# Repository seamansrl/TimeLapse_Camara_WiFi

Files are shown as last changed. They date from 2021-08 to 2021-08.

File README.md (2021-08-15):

# CAMARA TIMELAPSE CON GESTION WIFI

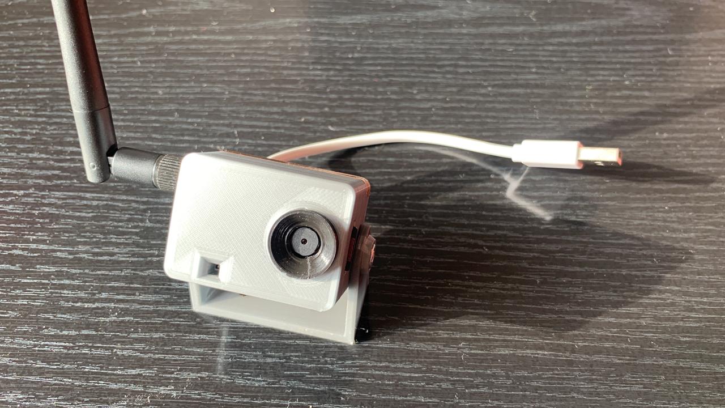
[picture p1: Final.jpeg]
Camara terminada


# Primeros pasos:

Antes de empezar deberemos bajar el proyecto a nuestra PC. Hay en él dos carpetas: una llamada CODIGO y otra llamada CHASIS. En Código esta el programa que deberemos cargar a nuestra ESP32-CAM y en chasis los modelos STL para imprimir la carcaza. 

# Elementos a utilizar

- ESP32-CAM modelo AI_THINKER (El código sirve para cualquier camara pero el chasis solo para esa)
- Antena con pigtail con conector micro para ESP32-CAM (Si se pone la antena externa de deberá cambiar de posición la resistencia interna. Ver más aca: https://randomnerdtutorials.com/esp32-cam-connect-external-antenna/)
- Tornillo rosca métrica de 1/8, 5cm con tuerca
- Cable rojo y negro 
- Conector USB
- Cargador USB de 2,5A
- MicroSD de 32GB formateada en FAT32

# Impresión del chasis

- Es importante imprimir el chasis con una altura de capa de 0,16mm máximo ya que mas allá de este punto puede que la placa no entre o queden las piezas fuera de lugar.
- La velocidad de impresión recomendada es de 40mm/s máximo para obtener buena terminación.
- No se requieren soportes.
- El parasol si se hace de un PLA con un coeficiente de fusion distinto al del chasis puede que cueste que entre ya que la rosca es muy chica. (ISO 17mm con paso de 0,75mm 3 espiras)

# Como cargar el código en la ESP32-CAM

Para copiar el código a la ESP32-Cam se requiere de un adaptador USB-TTL el cual ira conectado de la siguiente manera:

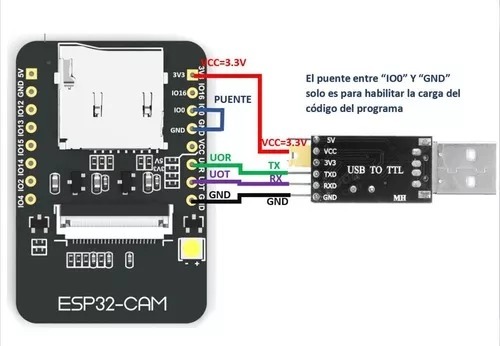
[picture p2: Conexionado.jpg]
Conexion entre TTL y ESP32-Cam


La configuración del entorno arduino para la carga sera:

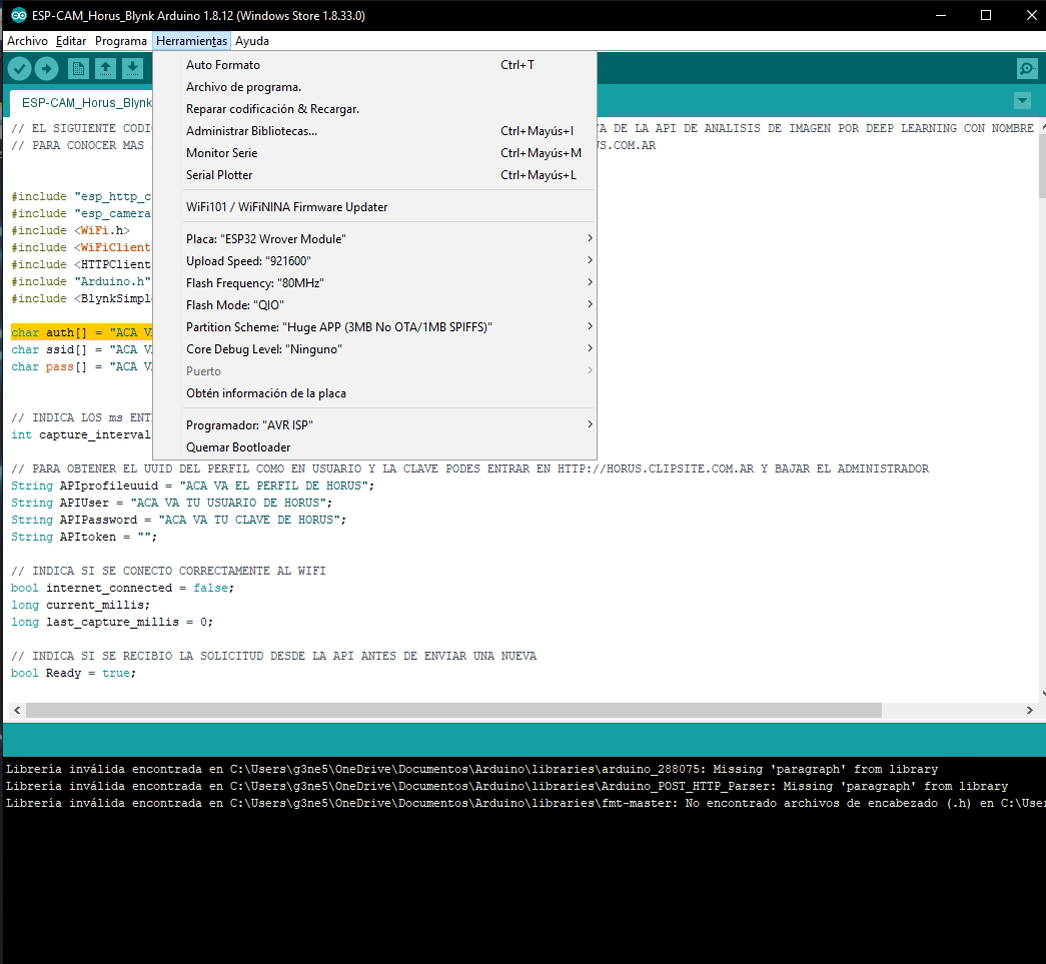
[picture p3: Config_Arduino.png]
Configuracion en entorno Arduino


Nota: Si hay problemas para subir el código a la placa y todo parase corresponder correctamente deberá probar invirtiendo el RX y el TX de la placa TTL.

# Configuración en tiempo de ejecución 

Una vez que el código este compilado y cargado a la ESP32, podremos configurar los parámetros de la camara usando un archivo “JSON” de nombre “config.json”. Desde este podremos cambiar los ajustes de imagen según la siguiente tabla: 

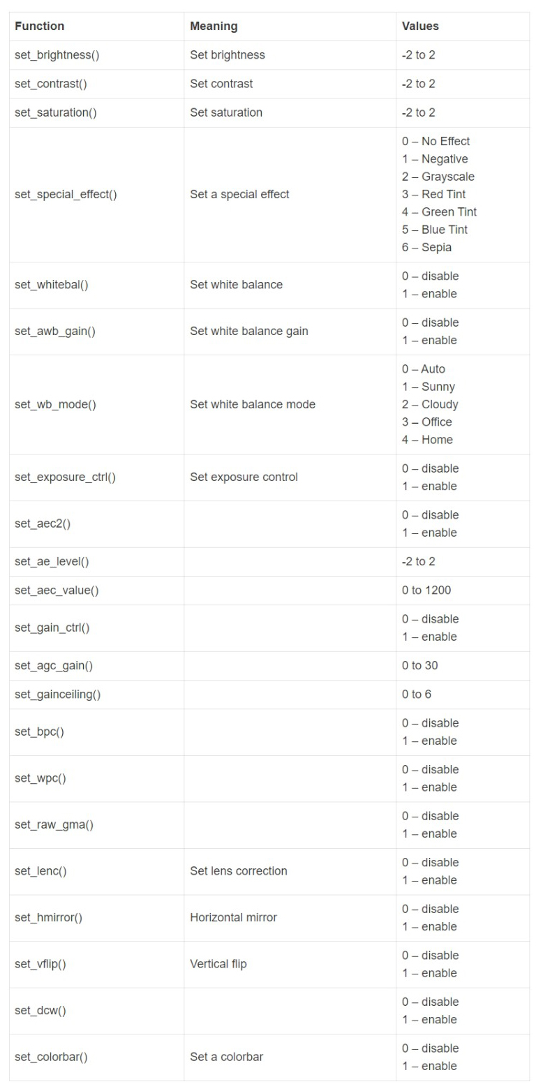
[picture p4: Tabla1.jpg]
Tabla de configuración de imagen


Como asi también los valores del SSID que tendrá el AP WiFi y el tiempo entre cuadros quedando de esta forma:

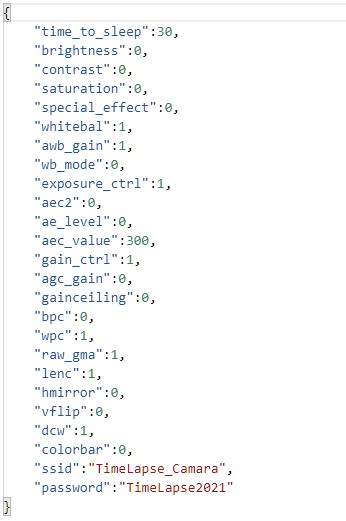
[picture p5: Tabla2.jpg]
Configuración json


Nota: Si bien en el proyecto dejo un archivo “config.json” el cual se deberá pegar en el raíz de la MicroSD, esto no es un paso indispensable ya que si dicho archivo no se encuentra se aplicara una configuración por defecto.

# Modo de uso

Una vez energizada la placa usando los cables y el conector USB solicitados en el apartado “Elementos a utilizar”, la placa iniciara con un destello en el LED del flash obteniendo el primer frame e indicando que todo esta OK. Pasado este punto y si se deja la configuración por defecto podremos conectáramos a la camara como si esta fuera un Router WiFi buscando la red “TimeLapse_Camara” y usando la clave “TimeLapse2021”.
Una vez conectados podremos abrir nuestro navegador de internet e ir a la pagina http://192.168.4.1 la cual nos abrirá una interfaz muy discreta en la cual veremos el tiempo entre frames, si la camara opera bien, cuantos frames tenemos en memoria y nos dará la posibilidad de acceder al FTP para descargar los archivos como asi también borrar la SD.

# Haciendo un video TimeLapse

La camara nos obtendra X cantidad de forogramas, cada uno de ellos corresponde a 1/30 segundos de video por lo cual 1 segundo implicara 30 cuadro. Con todo esto iremos a algun programa de video gratuito como https://www.virtualdub.org/ o pago como el Adobe Premier, importaremos los fotogramas y exportaremos el video terminado en formato que querramos: AVI, MP4, MOV, OGG, etc.

# Contactanos en:
https://www.linkedin.com/company/35599193/admin/

# Seguime en:
https://www.linkedin.com/in/fernando-p-maniglia/

# Conocenos más en:
https://www.seamansrl.com.ar

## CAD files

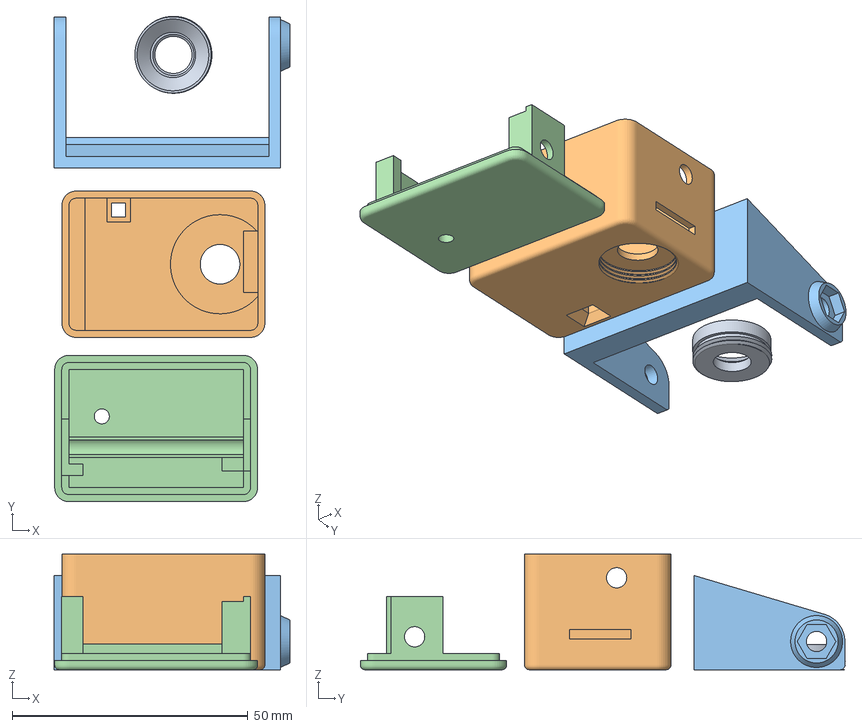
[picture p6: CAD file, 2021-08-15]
Chasis/Full para Cura.3mf
50.0 x 102.8 x 24.5 mm
parasol.stl
Chasis con antena.stl
Montura.stl
Tapa tracera.stl

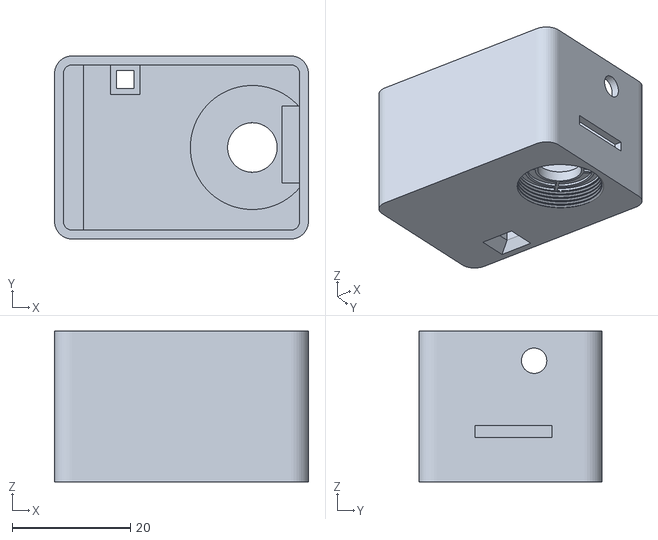
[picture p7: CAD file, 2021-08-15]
Chasis/chasis simple.stl
43.0 x 31.0 x 25.5

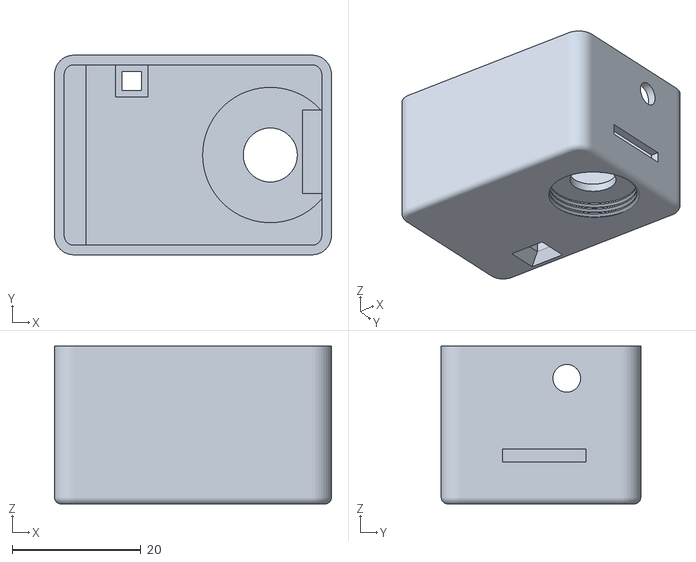
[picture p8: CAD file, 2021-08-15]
Chasis/Chasis con antena.stl
43.0 x 31.0 x 24.5

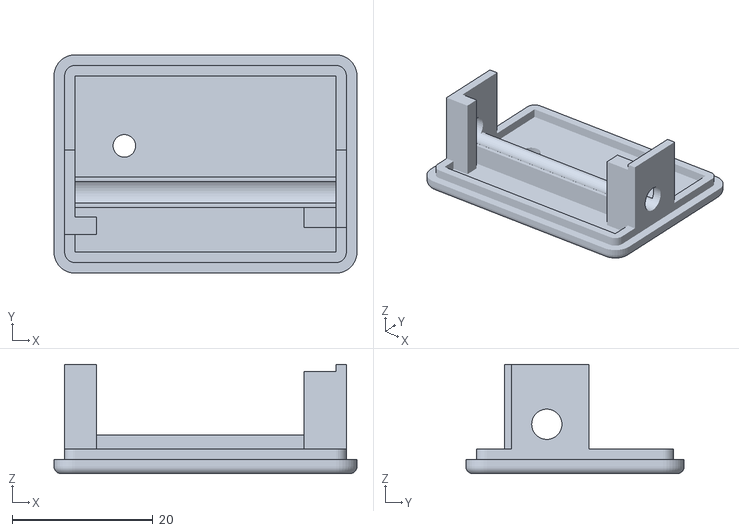
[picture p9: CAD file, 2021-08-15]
Chasis/Tapa tracera.stl
43.0 x 31.0 x 15.5

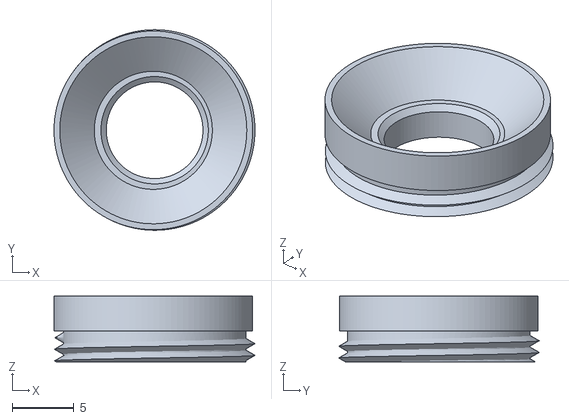
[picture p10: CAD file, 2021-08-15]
Chasis/parasol.stl
16.3 x 16.3 x 5.34

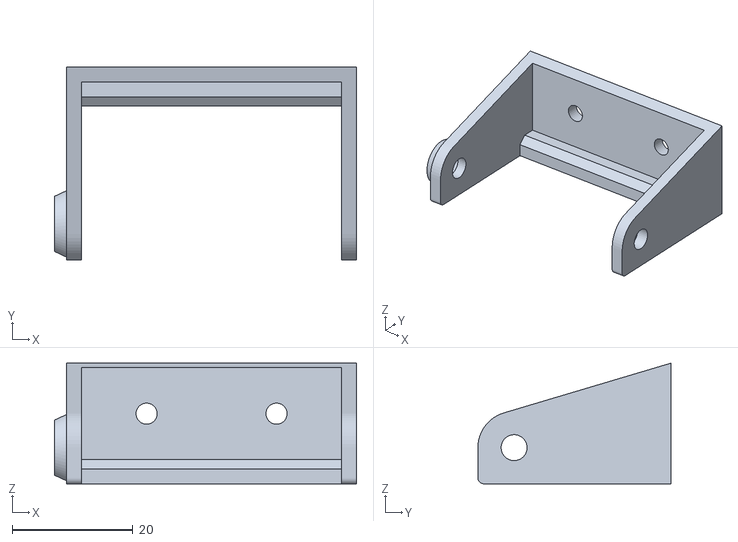
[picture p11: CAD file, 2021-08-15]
Chasis/Montura.stl
50.0 x 32.0 x 20.0

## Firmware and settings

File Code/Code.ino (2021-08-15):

// PROYECTO DESARROLLADO POR SEAMAN SRL
// EL PRESENTE CODIGO SE ENTREGA SIN GARANTIA ALGUNA

// Segun el tipo de camara la distribucion de pines varia por lo cual usando como referencia el archivo CAMARA_PINS.H deberemos elegir la que corresponda
#define CAMERA_MODEL_AI_THINKER

// Defino las variables a usar en la EEPROM para almacenar el fotograma por el que estamos en caso de que se reinicie la camara
#define ID_ADDRESS            0x00
#define COUNT_ADDRESS         0x01
#define ID_BYTE               0xAA
#define EEPROM_SIZE           0x0F

// Declaramos las librerias, salvando ArduinoJson.h todas las demas estan incluidas en el pack de la ESP32
#include "esp_camera.h"
#include <FS.h>
#include "SD_MMC.h"
#include "EEPROM.h"

// Se instala siguiendo estos pasos: https://arduinojson.org/v6/doc/installation/
#include <ArduinoJson.h>
#include "soc/soc.h"
#include "soc/rtc_cntl_reg.h"
#include <WiFi.h>
#include <WiFiClient.h>
#include <WiFiAP.h>
#include "ESP32FtpServer.h"
#include "camera_pins.h"

// Defino como calor por defecto entre cuadros 10 segundos, este valor lo podremos modificar en tiempo de ejecucion usando el archivo JSON
int TIME_TO_SLEEP = 10;
double Contador = 0;

uint16_t nextImageNumber = 0;

// Inicio la variable para el servidor FTP
FtpServer ftpSrv;

// Creo las variables de configuracion estandar para la camara, estas podran ser modificadas en tiempo de ejecucion usando el archivo JSON
int brightness = 0;         // -2 to 2
int contrast = 0;           // -2 to 2
int saturation = 0;         // -2 to 2
int special_effect = 0;     // 0 to 6 (0 - No Effect, 1 - Negative, 2 - Grayscale, 3 - Red Tint, 4 - Green Tint, 5 - Blue Tint, 6 - Sepia)
int whitebal = 1;           // 0 = disable , 1 = enable
int awb_gain = 1;           // 0 = disable , 1 = enable
int wb_mode = 0;            // 0 to 4 - if awb_gain enabled (0 - Auto, 1 - Sunny, 2 - Cloudy, 3 - Office, 4 - Home)
int exposure_ctrl = 1;      // 0 = disable , 1 = enable
int aec2 = 0;               // 0 = disable , 1 = enable
int ae_level = 0;           // -2 to 2
int aec_value = 300;       // 0 to 1200
int gain_ctrl = 1;          // 0 = disable , 1 = enable
int agc_gain = 0;          // 0 to 30
int gainceiling = 0;        // 0 to 6
int bpc = 0;                // 0 = disable , 1 = enable
int wpc = 1;                // 0 = disable , 1 = enable
int raw_gma = 1;            // 0 = disable , 1 = enable
int lenc = 1;               // 0 = disable , 1 = enable
int hmirror = 0;            // 0 = disable , 1 = enable
int vflip = 0;              // 0 = disable , 1 = enable
int dcw = 1;                // 0 = disable , 1 = enable
int colorbar = 0;           // 0 = disable , 1 = enable

// Creo las variables de configuracion para el AP WiFi, estas podran ser modificadas en tiempo de ejecucion usando el archivo JSON
String ssid = "TimeLapse_Camara";
String password = "TimeLapse2021";

String ConfigFile = "";

// Inicio el servidor WEB
WiFiServer server(80);

// Funcion de recurso, sirve para separar STRINGS segun un caracter especificado
String Split(String data, char separator, int index)
{
    int found = 0;
    int strIndex[] = {0, -1};
    int maxIndex = data.length()-1;
    
    for(int i=0; i<=maxIndex && found<=index; i++)
    {
          if(data.charAt(i)==separator || i==maxIndex)
          {
                found++;
                strIndex[0] = strIndex[1]+1;
                strIndex[1] = (i == maxIndex) ? i+1 : i;
          }
    }
    
    return found>index ? data.substring(strIndex[0], strIndex[1]) : "";
}

// Funcion de recurso, sirve para convertir variables de tipo String a tipo *char
char* string2char(String command)
{
    if(command.length()!=0)
    {
        char *p = const_cast<char*>(command.c_str());
        return p;
    }
}

// Funcion de sistema: Borra la memoria EEPROM para volver al contador a cero
void CleanEEPROM()
{
  Serial.println("Erasing EEPROM...");
  for(int i = 0; i < EEPROM_SIZE; i++)
  {
    EEPROM.write(i, 0xFF);
    EEPROM.commit();
    delay(20);
  }
  Serial.println("Erased");
}

// Funcion de sistema: Borra todos los archivos .JPG de la SD
void deleteImages(File dir, int numTabs)
{
  while (true)
  {
    File entry =  dir.openNextFile();
    if (! entry)
    {
      break;
    }

    if (entry.name() != "")
    {
      String FileType = Split(entry.name(), '.', 1);
      FileType.toUpperCase();
      
      if (FileType == "JPG")
        SD_MMC.remove(entry.name());
    }
    entry.close();
  }

  Serial.println("Images deleted");
}

// Funcion de sistema: Cuanta la cantidad de imagenes en la SD
double CountImages(File dir, int numTabs)
{
  double Images = 0;
  
  while (true)
  {
    File entry =  dir.openNextFile();
    if (! entry)
    {
      break;
    }

    if (entry.name() != "")
    {
      String FileType = Split(entry.name(), '.', 1);
      FileType.toUpperCase();
      
      if (FileType == "JPG")
        Images++;
    }
    entry.close();
  }

  return Images;
}

// Funcion de sistema: Obtiene la configuracion del archivo CONFIG.JSON y la asigna a las variables locales
void GetConfig(fs::FS &fs, const char * path)
{
  try
  {             
    File file = fs.open(path);
    if(!file)
    {
        Serial.println("CONFIG FAIL");
        return;
    }

    ConfigFile = "";
    
    while(file.available())
        ConfigFile = ConfigFile + String(char(file.read()));

    file.flush();
    file.close();
    
    const size_t bufferSize = ConfigFile.length() + 1024;
    
    DynamicJsonDocument doc(bufferSize);
    deserializeJson(doc, ConfigFile);
    JsonObject obj = doc.as<JsonObject>();

    if (ConfigFile != "")
    {

        if (obj["time_to_sleep"].as<int>() == NULL)
          TIME_TO_SLEEP = 10;
        else
        {
          TIME_TO_SLEEP = obj["time_to_sleep"].as<int>();

          if (TIME_TO_SLEEP < 10)
            TIME_TO_SLEEP = 10;
        }
        
        if (obj["brightness"].as<int>() == NULL) 
          brightness = 0;
        else
          brightness = obj["brightness"].as<int>();
        
        if (obj["contrast"].as<int>() == NULL) 
          contrast = 0; 
        else
          contrast = obj["contrast"].as<int>();
        
        if (obj["saturation"].as<int>() == NULL) 
          saturation = 0;
        else
          saturation = obj["saturation"].as<int>();
        
        if (obj["special_effect"].as<int>() == NULL) 
          special_effect = 0;
        else
          special_effect = obj["special_effect"].as<int>();
        
        if (obj["whitebal"].as<int>() == NULL) 
          whitebal = 1;
        else
          whitebal = obj["whitebal"].as<int>();
        
        if (obj["awb_gain"].as<int>() == NULL) 
          awb_gain = 1;
        else
          awb_gain = obj["awb_gain"].as<int>();
        
        if (obj["wb_mode"].as<int>() == NULL) 
          wb_mode = 0;
        else
          wb_mode = obj["wb_mode"].as<int>();
        
        if (obj["exposure_ctrl"].as<int>() == NULL) 
          exposure_ctrl = 1;
        else
          exposure_ctrl = obj["exposure_ctrl"].as<int>();
        
        if (obj["aec2"].as<int>() == NULL) 
          aec2 = 0;
        else
          aec2 = obj["aec2"].as<int>();
        
        if (obj["ae_level"].as<int>() == NULL) 
          ae_level = 0; 
        else
          ae_level = obj["ae_level"].as<int>();
        
        if (obj["aec_value"].as<int>() == NULL) 
          aec_value = 300;
        else
          aec_value = obj["aec_value"].as<int>();
        
        if (obj["gain_ctrl"].as<int>() == NULL)   
          gain_ctrl = 1;
        else
          gain_ctrl = obj["gain_ctrl"].as<int>();
        
        if (obj["agc_gain"].as<int>() == NULL) 
          agc_gain = 0;
        else
          agc_gain = obj["agc_gain"].as<int>();
        
        if (obj["gainceiling"].as<int>() == NULL) 
          gainceiling = 0;
        else
          gainceiling = obj["gainceiling"].as<int>();
        
        if (obj["bpc"].as<int>() == NULL) 
          bpc = 0;
        else
          bpc = obj["bpc"].as<int>();
        
        if (obj["wpc"].as<int>() == NULL) 
          wpc = 1;
        else
          wpc = obj["wpc"].as<int>();
        
        if (obj["raw_gma"].as<int>() == NULL) 
          raw_gma = 1;
        else
          raw_gma = obj["raw_gma"].as<int>();
        
        if (obj["lenc"].as<int>() == NULL) 
          lenc = 1;
        else
          lenc = obj["lenc"].as<int>();
        
        if (obj["hmirror"].as<int>() == NULL) 
          hmirror = 0;
        else
          hmirror = obj["hmirror"].as<int>();
        
        if (obj["vflip"].as<int>() == NULL) 
          vflip = 0;
        else
          vflip = obj["vflip"].as<int>();
        
        if (obj["dcw"].as<int>() == NULL) 
          dcw = 1;
        else
          dcw = obj["dcw"].as<int>();
        
        if (obj["colorbar"].as<int>() == NULL) 
          colorbar = 0;
        else
          colorbar = obj["colorbar"].as<int>();  

        if (obj["ssid"].as<String>() == "null")
          ssid = "TimeLapse_Camara";
        else
          ssid = obj["ssid"].as<String>();
          
        if (obj["password"].as<String>() == "null")
          password = "TimeLapse2021";  
        else
          password = obj["password"].as<String>();
    }
    
    sensor_t * s = esp_camera_sensor_get();
  
    s->set_brightness(s, brightness);
    s->set_contrast(s, contrast);
    s->set_saturation(s, saturation);
    s->set_special_effect(s, special_effect);
    s->set_whitebal(s, whitebal);
    s->set_awb_gain(s, awb_gain);
    s->set_wb_mode(s, wb_mode);
    s->set_exposure_ctrl(s, exposure_ctrl);
    s->set_aec2(s, aec2);
    s->set_ae_level(s, ae_level);
    s->set_aec_value(s, aec_value);
    s->set_gain_ctrl(s, gain_ctrl);
    s->set_agc_gain(s, agc_gain);
    s->set_gainceiling(s, (gainceiling_t)gainceiling);
    s->set_bpc(s, bpc);
    s->set_wpc(s, wpc);
    s->set_raw_gma(s, raw_gma);
    s->set_lenc(s, lenc);
    s->set_hmirror(s, hmirror);
    s->set_vflip(s, vflip);
    s->set_dcw(s, dcw);
    s->set_colorbar(s, colorbar);
  }
  catch(const std::exception& ex) 
  {
    Serial.println("FAIL ON: GetConfig");
  }
}

// Funcion de sistema: Atiende las solicitudes de los usuarios WEB y ejecuta la funcion de limpiado de SD y EEPROM
void WiFi_Clients()
{
  WiFiClient client = server.available();
  String currentLine = "";

  if (client) 
  {
    while (client.connected()) 
    {
      if (client.available()) 
      {
        char c = client.read();
        Serial.write(c);
        IPAddress dataIp = WiFi.softAPIP();  
        
        if (c == '\n') 
        {
          if (currentLine.length() == 0) 
          {
            client.println("HTTP/1.1 200 OK");
            client.println("Content-type:text/html");
            client.println();
            client.print("The Camara is active");
            client.print("<br>");
            client.print("Frames on SD: ");
            client.print(String(CountImages(SD_MMC.open("/"),0)));
            client.print("<br>");
            client.print("Lapse between frames: ");
            client.print(String(TIME_TO_SLEEP));
            client.print(" secons");
            client.print("<br>");
            client.print("Click <a href=\"ftp://" + ssid + ":" + password + "@" + String(dataIp[0]) + "." + String(dataIp[1]) + "." + String(dataIp[2]) + "." + String(dataIp[3]) + "\">here</a> to show files");
            client.print("<br>");
            client.print("Click <a href=\"/H\">here</a> to clean SD.<br>");
            client.println();
            break;
          } 
          else 
          {
            currentLine = "";
          }
        } 
        else if (c != '\r') 
        {
          currentLine += c;
        }

        if (currentLine.endsWith("GET /H")) 
        {
            deleteImages(SD_MMC.open("/"),0);
            CleanEEPROM();
    
            client.println("HTTP/1.1 200 OK");
            client.println("Content-type:text/html");
            client.println();
            client.print("The Camara is active");
            client.print("<br>");
            client.print("Frames on SD: ");
            client.print(String(CountImages(SD_MMC.open("/"),0)));
            client.print("<br>");
            client.print("Lapse between frames: ");
            client.print(String(TIME_TO_SLEEP));
            client.print(" secons");
            client.print("<br>");
            client.print("Click <a href=\"ftp://" + ssid + ":" + password + "@" + String(dataIp[0]) + "." + String(dataIp[1]) + "." + String(dataIp[2]) + "." + String(dataIp[3]) + "\">here</a> to show files");
            client.print("<br>");
            client.print("SD Cleaned<br>");
            client.println();

            break;
        }
      }
    }
    client.stop();
  }
}

void setup() 
{
  // Evita que la camara no inicie por caida de tension en la alimentación
  WRITE_PERI_REG(RTC_CNTL_BROWN_OUT_REG, 0);

  // Inicio el serial, en si esto no se usa mas que para debug
  Serial.begin(57600);
  Serial.println();
  Serial.println("Booting...");

  // Configuro los pines de la camara
  camera_config_t config;
  config.ledc_channel = LEDC_CHANNEL_0;
  config.ledc_timer = LEDC_TIMER_0;
  config.pin_d0 = Y2_GPIO_NUM;
  config.pin_d1 = Y3_GPIO_NUM;
  config.pin_d2 = Y4_GPIO_NUM;
  config.pin_d3 = Y5_GPIO_NUM;
  config.pin_d4 = Y6_GPIO_NUM;
  config.pin_d5 = Y7_GPIO_NUM;
  config.pin_d6 = Y8_GPIO_NUM;
  config.pin_d7 = Y9_GPIO_NUM;
  config.pin_xclk = XCLK_GPIO_NUM;
  config.pin_pclk = PCLK_GPIO_NUM;
  config.pin_vsync = VSYNC_GPIO_NUM;
  config.pin_href = HREF_GPIO_NUM;
  config.pin_sscb_sda = SIOD_GPIO_NUM;
  config.pin_sscb_scl = SIOC_GPIO_NUM;
  config.pin_pwdn = PWDN_GPIO_NUM;
  config.pin_reset = RESET_GPIO_NUM;
  config.xclk_freq_hz = 20000000;
  config.pixel_format = PIXFORMAT_JPEG;

  // Configuro la resolucion de cuadro
  if(psramFound())
  {
    config.frame_size = FRAMESIZE_UXGA;
    config.jpeg_quality = 10;
    config.fb_count = 2;
  } else 
  {
    config.frame_size = FRAMESIZE_SVGA;
    config.jpeg_quality = 12;
    config.fb_count = 1;
  }

  // Inicio la camara
  esp_err_t err = esp_camera_init(&config);
  if (err != ESP_OK) 
  {
    Serial.printf("Camera init failed with error 0x%x", err);
    return;
  }

  // Inicio la EEPROM
  if (!EEPROM.begin(EEPROM_SIZE))
  {
    Serial.println("Failed to initialise EEPROM"); 
    Serial.println("Exiting now"); 
    while(1);
  }

  // Inicio la SD
  if(SD_MMC.begin("/sdcard",false) == true)
  {
    if(SD_MMC.cardType() == CARD_NONE)
    {
      Serial.println("No SD card attached");
      return;
    }  
  }
  else
  {
    Serial.println("Card Mount Failed");

    CleanEEPROM();
  
    return;
  }

  // Obtengo la configuracion de la SD
  GetConfig(SD_MMC, "/config.json");

  // Inicio el AP WiFi
  WiFi.softAP(string2char(ssid), string2char(password));
  IPAddress myIP = WiFi.softAPIP();
  Serial.print("AP IP address: ");
  Serial.println(myIP);

  // Inicio el servidor FTP
  ftpSrv.begin(ssid, password);

  // Inicio el servidor WEB
  server.begin();
}

void loop() 
{
  // Si el contaodor esta en 0 tomo un cuadro
  if (Contador == 0)
  {
    if(EEPROM.read(ID_ADDRESS) != ID_BYTE)
    {
      Serial.println("Initializing ID byte & restarting picture count");
      nextImageNumber = 0;
      EEPROM.write(ID_ADDRESS, ID_BYTE);  
      EEPROM.commit(); 
    }
    else
    {
      EEPROM.get(COUNT_ADDRESS, nextImageNumber);
      nextImageNumber +=  1;    
    }
  
    camera_fb_t * fb = NULL;
  
    fb = esp_camera_fb_get();
    if (!fb) 
    {
      Serial.println("Camera capture failed");
      Serial.println("Exiting now"); 
      while(1);
    }
    
    String path = "/IMG" + String(nextImageNumber) + ".jpg";
      
    File file = SD_MMC.open(path.c_str(), FILE_WRITE);
    if(!file)
    {
      Serial.println("Failed to create file");
      Serial.println("Exiting now"); 
      while(1);   //wait here as something is not right    
    } 
    else 
    {
      file.write(fb->buf, fb->len); 
      EEPROM.put(COUNT_ADDRESS, nextImageNumber);
      EEPROM.commit();
    }
    file.close();

    esp_camera_fb_return(fb);
    Serial.printf("Image saved: %s\n", path.c_str());
  }

  delay(10);
  Contador++;

  // Atiendo solicitudes WEB y FTP
  ftpSrv.handleFTP();
  WiFi_Clients();

  // Si llego a la cantidad de segundos asignado pongo el contador en 0
  if (Contador > TIME_TO_SLEEP * 100)
    Contador = 0;
}
